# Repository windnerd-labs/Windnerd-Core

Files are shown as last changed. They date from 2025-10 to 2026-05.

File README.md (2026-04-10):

# WindNerd Core - Open Source Sensor & Development Board for 3D-Printed Anemometers

## Intro

The WindNerd Core is a **full magnetic** sensor board designed to fit inside the [**WindNerd 3D-printed-anemometer**](https://github.com/windnerd-labs/Anemometer-3D-files).

It is [**available as a kit**](https://windnerd.net/en/shop), which includes the board and essential parts like magnets and bearings.

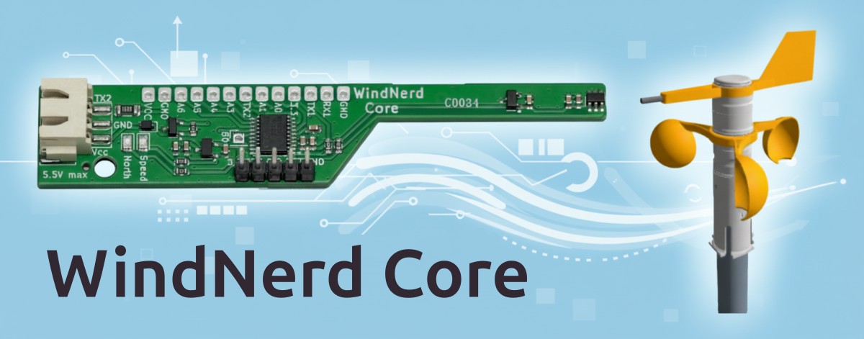
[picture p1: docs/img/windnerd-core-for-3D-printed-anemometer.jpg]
WindNerd Core Sensor/Dev board for 3D-printed anemometer


You can use it as a dedicated wind **sensor module** for your weather station, or as an **Arduino compatible development board** that can, for example:

- Control peripherals such as a [LTE modem](examples/02-lte-modem-A7670X/) to send data remotely
- Drive LEDs that blink according to wind speed and direction
- Interface with other sensors (e.g., temperature, humidity, pressure)

For development, an ST-Link V2 (or compatible) dongle is recommended. However, alternative firmwares can also be uploaded via a serial bootloader.

## Factory Firmware

The board is shipped with factory firmware that outputs instant wind values and averaged wind values over a serial connection.

The average power consumption is only **0.6mA** (3.3V or 5V).

It can be connected to a computer using a **USB-serial-TTL adapter** or to any MCU board that provides a **UART serial interface**.

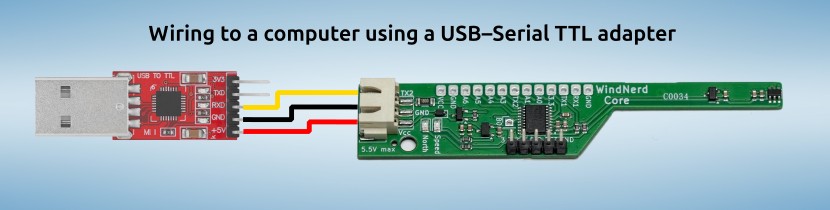
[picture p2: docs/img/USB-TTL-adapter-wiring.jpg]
Wiring WindNerd Core to computer using USB-serial-TTL adapter


The baudrate is 9600bps 8N1. This configuration allows fairly long wiring, e.g. to reach the top of a pole.  

Two types of messages are provided, the default speed unit is km/h and values are averaged for the last 10 minutes:  

**Instant wind** (every 3 Sec)

`WNI,<speed>,<direction 0-359>`
ex: `WNI,10.4,149`  

**Average wind report** (every minute)

`WNA,<speed avg>,<direction avg 0-359>,<min speed>,<max speed>`
ex: `WNA,12.2,93,0,21.4`  

The factory firmware is based on an [Arduino example sketch](examples/01-factory-v1/01-factory-v1.ino) that can be easily tweaked to your own needs.

[**How to read serial data from another device**](docs/READSERIAL.md)

## Arduino library

This repository provides an Arduino library that implements a driver for the magnetic sensors and computes wind speed and direction, exposing the values through a simple API.

[**How to install WindNerd Core library and program the board**](docs/PROGRAM.md)

[**WindNerd Core API reference**](docs/API-REFERENCE.md)

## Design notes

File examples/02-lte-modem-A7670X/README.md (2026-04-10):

# LTE Cat-1 (4G) modem SIMCOM A7670X

## Intro
This example demonstrates how to use a SIMCOM A7670X LTE Cat-1 modem to upload wind data every 2 minutes using the [WindNerd Transfer Protocol](../../docs/WTP.md).

Between uploads modem is is placed into sleep mode to minimize power consumption. Measured system average is ~6 mA to 12mA under good LTE coverage, enabling operation from a single 18650 cell recharged via a small solar panel.

Data consumption is about 40MB per month.

Most SIMCOM and Quectel LTE modems using standard AT command sets should also work with minimal adaptation.

## LTE module

The A7670X exists in multiple regional versions based on LTE band support:

- A7670E Europe, Asia
- A7670SA South America
- A7670G Global

Typical module pricing ranges $10–$25 depending on version.

In this guide we use a A7670E module available for ~$13 on [Aliexpress](https://www.aliexpress.com/item/1005004176439432.html) under the brand "and-global".

## Wiring

### Powered from 5V
The module includes an onboard regulator and can be powered directly from 5V alongside the WindNerd Core. 

Always connect an antenna when powering the module up. 

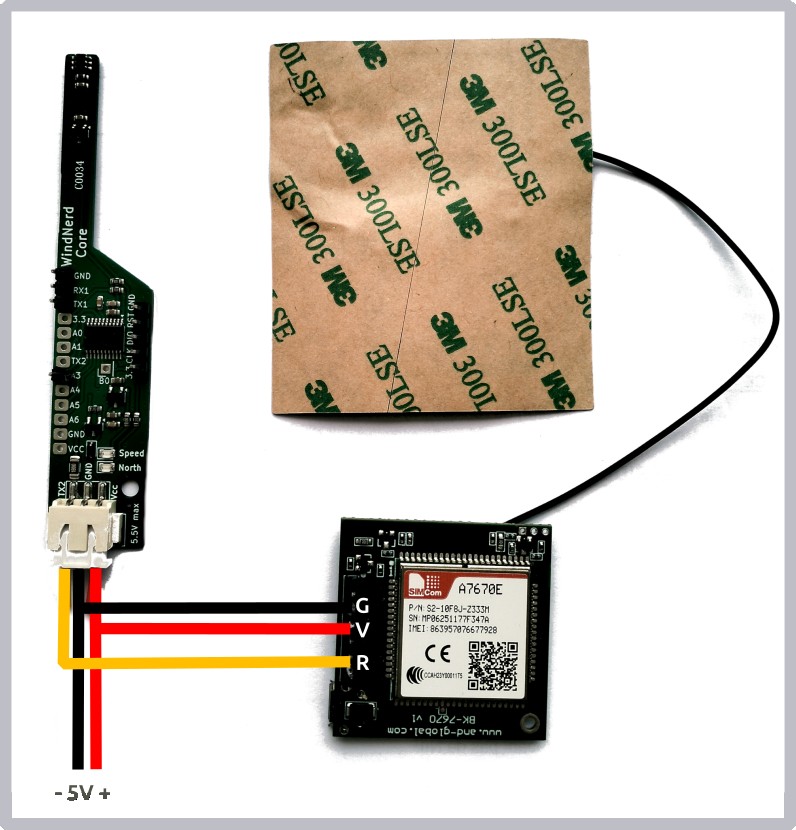
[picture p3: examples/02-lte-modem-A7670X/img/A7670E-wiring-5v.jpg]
Wiring 5V


### Powered from 1 lithium cell

For better efficiency, the A7670X chipset can be powered directly on lithium battery after a little modification on the module. We bypass the inefficient linear voltage regulator and remove a resistance that wastes too much current to the ground.

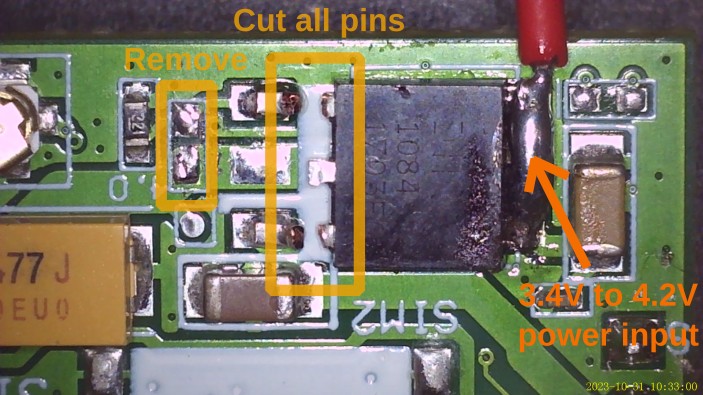
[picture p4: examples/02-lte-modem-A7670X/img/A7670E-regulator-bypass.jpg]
Regulator bypass


Now the battery positive wire should be soldered directly on the board.

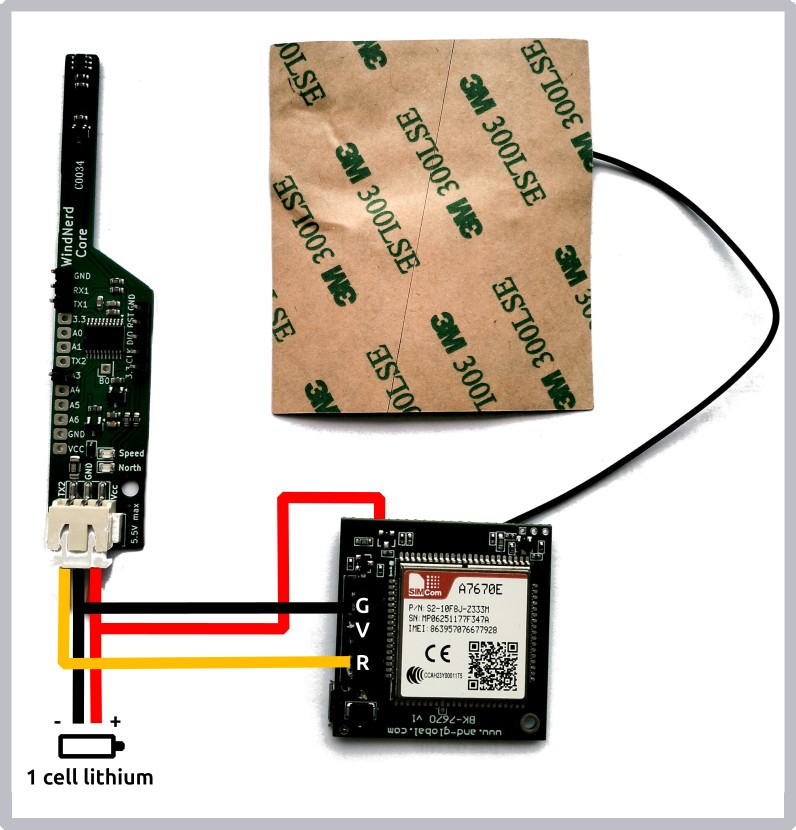
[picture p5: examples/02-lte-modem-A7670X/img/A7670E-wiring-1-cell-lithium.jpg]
Wiring 1-cell Lithium


## WindNerd Core Programming

Open lte-modem-A7670X example sketch, find the line below and replace the secret key with one available on your [windnerd.net dashboard](https://windnerd.net/en/management):

`#define WTP_SECRET_KEY "af3ffa12c4937ddf"`

[Compile and upload](../../docs/PROGRAM.md) the sketch to your WindNerd Core

It may be necessary to specify the APN for the network in use. For example, if you use a Hologram IoT SIM card, uncomment the line and set the APN as follows:

`#define APN "hologram"`

## Commissioning

When powered with a SIM card inserted, the module will automatically attach to the network even without WindNerd Core connected.

On-board LED behavior:

| LED State | Meaning |
| --- | --- |
| On solid after startup | Module boot OK |
| Fast blinking | Connected and data service available |
| OFF | Module powered down or in sleep mode |

Around 2 minutes after powering-up, the station set for your device will show live wind data.

## Power Voltage measurement

It is possible to additionally monitor the supply voltage by soldering two 22 kΩ resistors (or other identical values in the same range, such as 47 kΩ) as a voltage divider between **GND–PB0–VCC**.
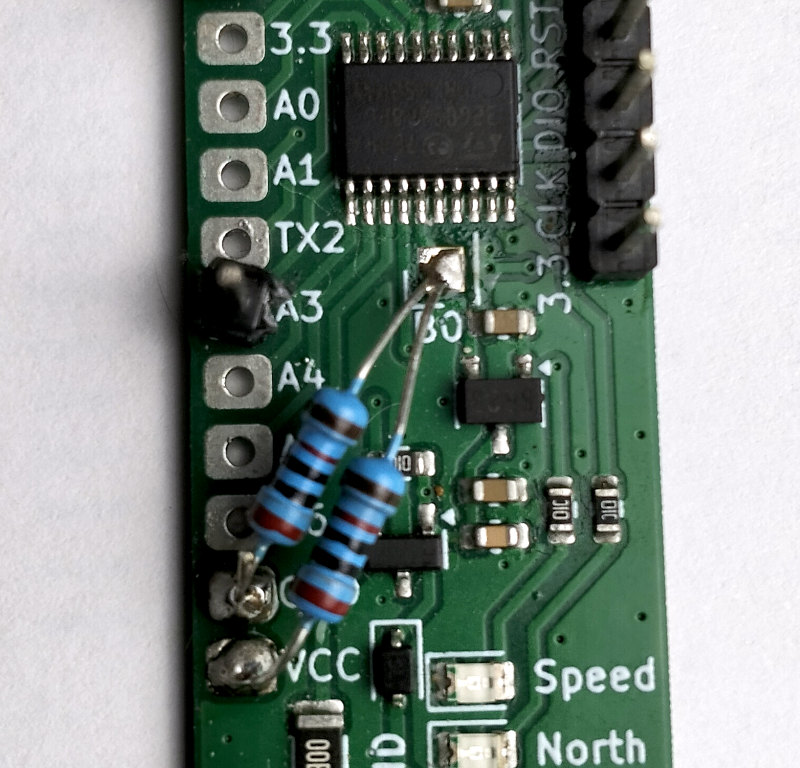
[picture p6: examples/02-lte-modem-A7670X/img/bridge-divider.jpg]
22K resistors soldered on dev board


Uncomment the following line in the sketch to activate the feature
```
#define ENABLE_VOLTAGE
```

## Temperature, humidity, atmospheric pressure measurement

Temperature, humidity, and atmospheric pressure can be monitored by adding a BME280 sensor (or compatible equivalent like BMP280 or YMP280) on the secondary I²C bus, which shares the same pins as USART1. Without a **radiation shield**, temperature and humidity measurements may not be very accurate.

| USART1    | I2C2
 | -----|------- |
| TX1 | SCL2 |
| RX1 | SDA2|

BME280 is powered from GND-3.3V pin headers.

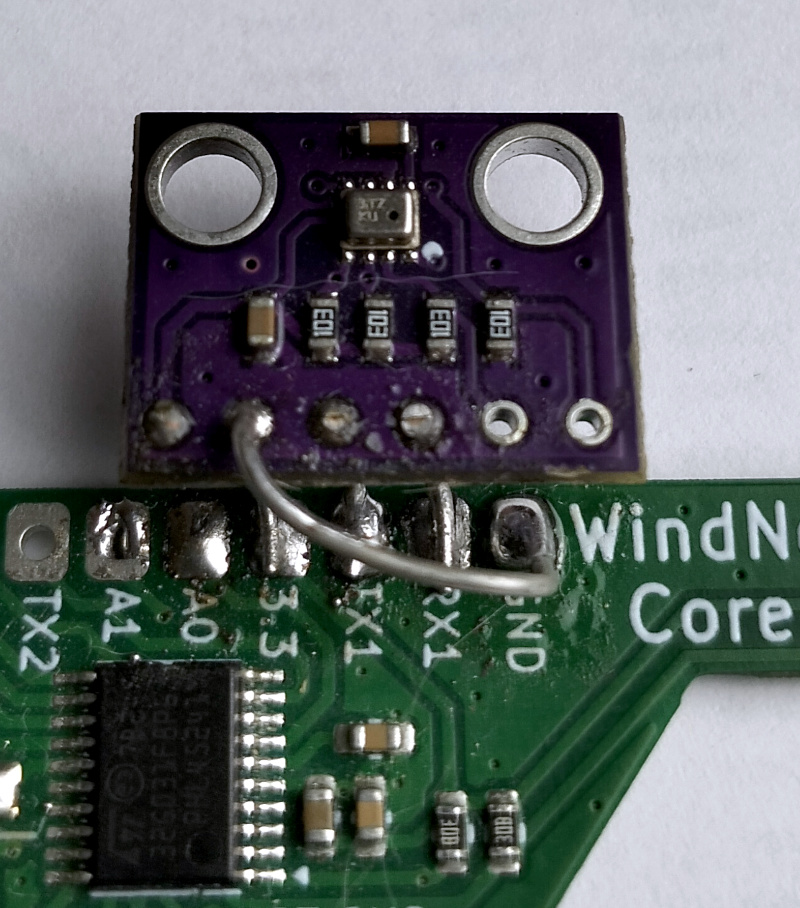
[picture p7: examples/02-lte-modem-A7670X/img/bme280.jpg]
bme280 added to dev board


The Arduino library `Bme280 by Eduard Malokhvii` is required.

Uncomment the following line in the sketch to activate the feature
```
#define ENABLE_BME_280
```

## Debugging (Reading AT Responses)

To inspect the modem’s AT command responses, you can connect a USB-Serial (TTL) adapter to the module’s UART Tx.
This allows you to watch live communication using a terminal such as PuTTY, Screen, or minicom.

| Serial-TTL adapter | A7670X module |
| --- | --- |
| Gnd | Gnd (G) |
| Rx  | Tx (T)  |

### Start-up
When the A7670X powers up with a valid SIM card, it will output several startup notifications.
A typical healthy boot sequence looks like this:

```
[2025-11-10 14:05:24] *ATREADY: 1
[2025-11-10 14:05:24] 
[2025-11-10 14:05:24] *ISIMAID: "A0000000871004F310FFFF89080000FF"
[2025-11-10 14:05:25] 
[2025-11-10 14:05:25] +CPIN: READY
[2025-11-10 14:05:29] 
[2025-11-10 14:05:29] SMS DONE
[2025-11-10 14:05:29] 
[2025-11-10 14:05:29] +CGEV: EPS PDN ACT 1

```

`+CGEV: EPS PDN ACT 1` indicates that the module is attached to network.

### Upload Sequence
Every upload cycle, the sketch sends a small HTTP POST request using the WindNerd Transfer Protocol.

Expected output during a successful upload:

```
[2025-11-10 14:07:19] AT
[2025-11-10 14:07:19] OK
[2025-11-10 14:07:19] AT+HTTPINIT
[2025-11-10 14:07:20] OK
[2025-11-10 14:07:20] AT+HTTPPARA="URL","http://wtp.windnerd.net/post"
[2025-11-10 14:07:20] OK
[2025-11-10 14:07:20] AT+HTTPDATA=765,10000
[2025-11-10 14:07:20] DOWNLOAD
[2025-11-10 14:07:20] 
[2025-11-10 14:07:20] OK
[2025-11-10 14:07:20] AT+HTTPACTION=1
[2025-11-10 14:07:20] OK
[2025-11-10 14:07:22] 
[2025-11-10 14:07:22] +HTTPACTION: 1,200,2
[2025-11-10 14:07:22] AT+HTTPTERM
[2025-11-10 14:07:22] OK
```
`+HTTPACTION: 1,200,2` indicates server responded with HTTP 200 OK

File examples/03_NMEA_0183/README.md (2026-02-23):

# NMEA0183 over serial

## Intro

With this sketch, the WindNerd Core emulates a NMEA 0183 compatible wind sensor.

The communication format follows the NMEA 0183 protocol (ASCII sentences such as $IIMWV,...). However, the electrical characteristics of the WindNerd Core serial output (0–3.3V UART logic level) are not compliant with the official NMEA 0183 electrical standard.

In this example, we connect the WindNerd Core to a computer (for example a Raspberry Pi) using a USB-to-TTL serial converter.

We then configure **Signal K** to treat this serial device as a NMEA 0183 input.

## SignalK configuration

On the Signal K web interface:

- Go to Server → Data Connections

- Click Add

- Create a connection as below

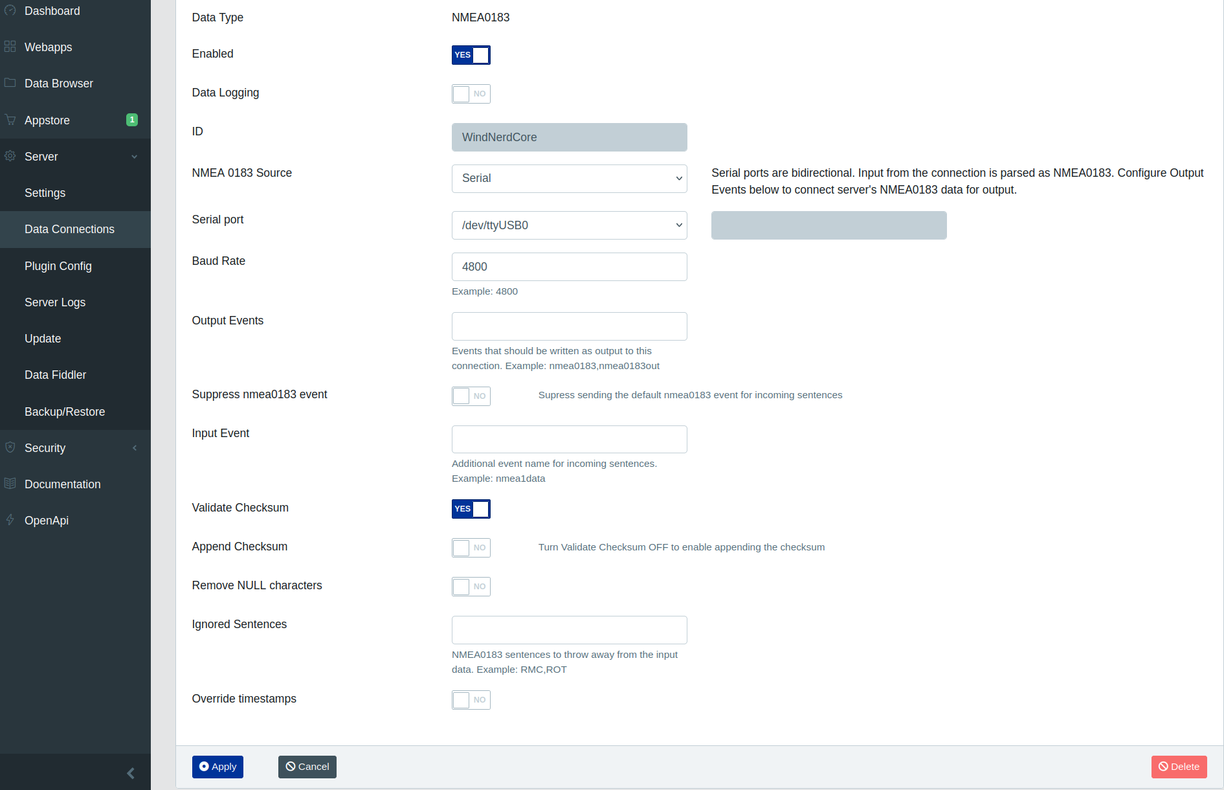
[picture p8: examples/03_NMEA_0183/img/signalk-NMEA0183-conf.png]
Signal K configuration for reading anemometer input


`/dev/ttyUSB0` may be different on your system

If the WindNerd Core is connected and transmitting, wind data should appear in:

Server → Data Browser

You should see path `environment.wind.speedApparent` and `environment.wind.angleApparent` refreshed every 3 seconds.

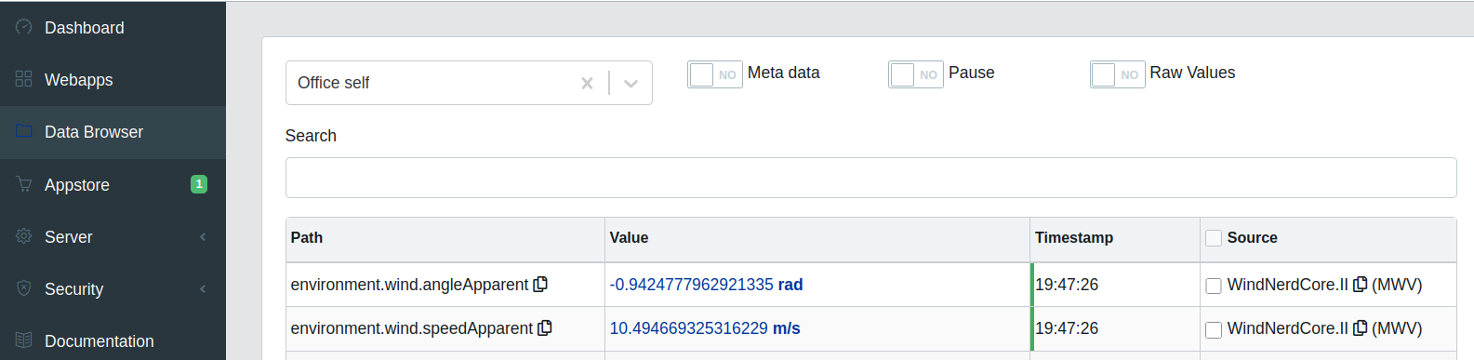
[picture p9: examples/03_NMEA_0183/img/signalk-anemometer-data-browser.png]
Wind data on signalk browser


If nothing appears, try to restart Signal-K server.

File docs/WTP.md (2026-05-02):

# WindNerd Transfer Protocol

## Introduction

The WindNerd Transfer Protocol (WTP) enables recording and broadcasting of fast-changing wind and other weather data even without a permanent internet connection.

Reports with intervals as short as 1 minute can be aggregated and sent in a single request to be recorded and published for your station on **windnerd.net**

High-frequency samples, every 3 seconds, can be sent in real-time or periodically aggregated to be replayed with a delay.

## Authentication

A 16 characters hexadecimal secret key is required, this key is available to WindNerd Core users in their [station management console](https://windnerd.net/en/management). Key can be regenerated at any time.

## Post data

#### Endpoint (use HTTPS if possible):

HTTPS: https://wtp.windnerd.net/post

HTTP:  http://wtp.windnerd.net/post

Two kinds of data can be posted:
 - reports: these reports are stored in windnerd.net database. Average, minimum, and maximum values over longer periods are derived from them.
 - high-frequency wind samples: these samples are broadcast in real time to visualize and feel the wind as it happens. Aggregated samples are queued for delayed replay.
 - logs: health data about the device: internal temperature, power voltage or free form logs.

#### JSON

**Method:** `POST`  
**Content-Type:** `application/json`  
**Responses:** `200 Request accepted`,  `400 Bad Request` or `401 Wrong Authentication`

```json
{
  "secret_key": "3122fd880084fd55",
  "interval_mn": 1,
  "wind_unit": "ms",
  "temp_unit": "C",
  "reports": [
    { "wind_avg": 3.1, "wind_dir": 90,  "wind_min": 0.5, "wind_max": 3.5, "temperature": 22, "humidity": 70, "pressure": 1012 }, // most recent
    { "wind_avg": 1.8, "wind_dir": 45,  "wind_min": 0.0, "wind_max": 2.0, "temperature": 28, "humidity": 85, "pressure": 1016 },
    { "wind_avg": 4.0, "wind_dir": 180, "wind_min": 1.0, "wind_max": 5.0, "temperature": 21, "humidity": 60, "pressure": 1010 },
    { "wind_avg": 2.0, "wind_dir": 200, "wind_min": 0.5, "wind_max": 2.5, "temperature": 23, "humidity": 72, "pressure": 1011 },
    { "wind_avg": 3.5, "wind_dir": 310, "wind_min": 1.5, "wind_max": 4.5, "temperature": 20, "humidity": 65, "pressure": 1009 } // most ancient
  ],
    "samples": [
    { "wind_inst": 3.1, "wind_dir": 90 }, // most recent
    { "wind_inst": 1.8, "wind_dir": 75 },
    { "wind_inst": 4.0, "wind_dir": 110 },
    { "wind_inst": 2.5, "wind_dir": 80 },
    { "wind_inst": 3.3, "wind_dir": 82 },
    { "wind_inst": 0.8, "wind_dir": 101 },
    { "wind_inst": 2.0, "wind_dir": 105 },
    { "wind_inst": 3.5, "wind_dir": 120 },
    { "wind_inst": 1.2, "wind_dir": 130 },
    { "wind_inst": 2.8, "wind_dir": 125 },
    { "wind_inst": 3.0, "wind_dir": 100 },
    { "wind_inst": 2.2, "wind_dir": 92 },
    { "wind_inst": 1.5, "wind_dir": 95 },
    { "wind_inst": 4.2, "wind_dir": 102 },
    { "wind_inst": 3.8, "wind_dir": 120 },
    { "wind_inst": 2.6, "wind_dir": 104 },
    { "wind_inst": 1.9, "wind_dir": 96 },
    { "wind_inst": 3.2, "wind_dir": 85 },
    { "wind_inst": 2.0, "wind_dir": 93 },
    { "wind_inst": 2.1, "wind_dir": 90 } // most ancient
  ],
  "logs": [
    { "voltage": 3.86, "temp_in": 38.2, "meta": "no error" },
    { "voltage": 3.85, "temp_in": 38.4, "meta": "no error" }
  ]
}
```

##### Parameters Fields

| Field | Alt. | Type | Required | Description |
| --- | ----- | --- | --- | --- |
| `secret_key`  | `k` | string  | Yes | Secret key for authentication |
| `interval_mn` | `i` | integer | No | Interval in minutes between reports (max: `60`, default: `1`) |
| `wind_unit` | `wu` | string  | No | Wind speed unit. Accepts `"kmh"`, `"ms"`, `"mph"` (default: `"ms"`) |
| `temp_unit` | `tu` | string  | No | Temperature unit. Accepts `"C"`, `"F"` (default: `"C"`) |
| `reports` | `r` | array | No\* | Array of aggregated reports (max: 20 items) |
| `samples` | `s` | array | No\* | Array of aggregated samples (max: 200 items) |
| `logs` | `l` | array | No\* | Array of aggregated logs (max: 10 items per 10 mn windows) |

\* At least one of `reports`, `samples`, or `logs` must be provided.

##### Report Fields

| Field | Alt. | Type | Required | Min  | Max  | Description |
| --- | ---- | --- | --- | ---- | ---- | --- |
| `wind_avg` | `wa` | number | Yes | 0 | 360  | Vector-averaged wind speed during the interval |
| `wind_min` | `wn` | number | Yes | 0 | 360  | Minimum wind speed during the interval |
| `wind_max` | `wx` | number | Yes | 0 | 360  | Maximum wind speed during the interval |
| `wind_dir` | `wd` | number | Yes | 0 | 360  | Average wind direction in degrees (0–359) |
| `temperature` | `tp` | number | No | -99  | 200  | Ambient temperature |
| `humidity` | `hu` | number | No | 0 | 100  | Relative humidity (%) |
| `pressure` | `pr` | number | No | 200  | 1100 | Atmospheric pressure (hPa) |

##### Sample Fields

| Field | Alt. | Type | Required | Min  | Max  | Description |
| --- | ---- | --- | --- | ---- | ---- | --- |
| `wind_inst` | `wi` | number | Yes | 0 | 360  | Wind speed during the 3 sec interval |
| `wind_dir` | `wd` | number | Yes | 0 | 360  | Wind direction during the 3 sec interval |

##### Log Fields

| Field | Alt. | Type | Required | Min  | Max  | Description |
| --- | ---- | --- | --- | ---- | ---- | --- |
| `voltage` | `vo` | number | No | 0 | 999  | Voltage (V) |
| `rssi` | `rs` | number | No | -999 | 999  | Signal strength indicator (RSSI) |
| `temp_in` | `ti` | number | No | -99  | 200  | Internal temperature |
| `meta` | `mt` | string | No | - | 512  | Free-form payload for debug or metadata. Maximum length: 512 characters. Allowed characters: printable ASCII (0x20–0x7E) except `,` `;` `=`. |

---

#### TEXT

**Method:** `POST`  
**Content-Type:** `text/plain`  
**Responses:** `200 Request accepted`,  `400 Bad Request` or `401 Wrong Authentication`

Alternatively, the payload can be encoded as plain text. 

The first line defines the parameters, and each subsequent line represents a report (line starting with `r`), a sample (line starting with `s`), or a log (line starting with `l`).

Lines are separated by semicolons; end-of-line and carriage return characters are optional.

Report, sample, and log lines must be ordered from most recent to most ancient.

```text
k=3122fd880084fd55,i=1,wu=ms,tu=C;
r,wa=3.1,wd=90,wn=0.5,wx=3.5,tp=22,hu=70,pr=1012;
r,wa=1.8,wd=45,wn=0.0,wx=2.0,tp=28,hu=85,pr=1016;
r,wa=4.0,wd=180,wn=1.0,wx=5.0,tp=21,hu=60,pr=1010;
r,wa=2.0,wd=200,wn=0.5,wx=2.5,tp=23,hu=72,pr=1011;
r,wa=3.5,wd=310,wn=1.5,wx=4.5,tp=20,hu=65,pr=1009;
l,vo=3.86,ti=38.2,mt=no error;
s,wi=3.1,wd=90;
s,wi=1.8,wd=75;
s,wi=4.0,wd=110;
s,wi=2.5,wd=80;
s,wi=3.3,wd=82;
s,wi=0.8,wd=101;
s,wi=2.0,wd=105;
s,wi=3.5,wd=120;
s,wi=1.2,wd=130;
s,wi=2.8,wd=125;
s,wi=3.0,wd=100;
s,wi=2.2,wd=92;
s,wi=1.5,wd=95;
s,wi=4.2,wd=102;
s,wi=3.8,wd=120;
s,wi=2.6,wd=104;
s,wi=1.9,wd=96;
s,wi=3.2,wd=85;
```

## Examples in context

### Permanent connection
A Raspberry Pi in a ceiling, connected to WindNerd Core, has continuous power and internet access. JSON format is handled easily and we can send data without limitation. 

We post high-frequency samples every 3 seconds:

```json
{
  "v": 1,
  "k": "3122fd880084fd55",
  "wind_unit": "ms",
  "samples": [
    { "wind_inst": 3.1, "wind_dir": 90 }
  ]
}
```

We post a report every minute:
```json
{
  "secret_key": "3122fd880084fd55",
  "interval_mn": 1,
  "wind_unit": "ms",
  "temp_unit": "C",
  "reports": [
    { "wind_avg": 3.1, "wind_dir": 90,  "wind_min": 0.5, "wind_max": 3.5, "temperature": 22, "humidity": 70, "pressure": 1012 },
  ]
}
```
---

### Limited radio use
A WindNerd Core is connected to a LoRa development board and installed at a paragliding takeoff. The LoRa receiver has permanent power and internet access, but fair-use limitations allow only one transmission per minute.

We connect every minute to send aggregated reports and high-frequency samples. To keep messages short and easy to construct, we use the plain-text format. Pilots can still see a real-time wind animation, with a 1-minute delay due to the transmission interval.

We post 20 samples and a report every minute:

```text
k=3122fd880084fd55,wu=ms;
r,wa=3.1,wd=90,wn=0.5,wx=3.5;
s,wi=3.1,wd=90;
s,wi=1.8,wd=75;
s,wi=4.0,wd=110;
s,wi=2.5,wd=80;
s,wi=3.3,wd=82;
s,wi=0.8,wd=101;
s,wi=2.0,wd=105;
s,wi=3.5,wd=120;
s,wi=1.2,wd=130;
s,wi=2.8,wd=125;
s,wi=3.0,wd=100;
s,wi=2.2,wd=92;
s,wi=1.5,wd=95;
s,wi=4.2,wd=102;
s,wi=3.8,wd=120;
s,wi=2.6,wd=104;
s,wi=1.9,wd=96;
s,wi=3.2,wd=85;
s,wi=2.0,wd=93;
s,wi=2.1,wd=90;
```
---

### Limited power

A WindNerd Core is connected to a 4G modem development board and installed at a remote location. Power is limited because it relies on a small solar cell and battery, and winter nights are long.

We activate a power-saving mode, making a connection only every 20 minutes. During each connection, we send 20 1-minute reports. Data are no longer real-time, but all detailed history is preserved.

We post 20 reports every 20 minute:

```text
k=3122fd880084fd55,i=1,wu=ms;
r,wa=2.1,wd=180,wn=1.0,wx=2.5,tp=0.2,hu=88,pr=1018.0;
r,wa=1.8,wd=190,wn=0.5,wx=2.0,tp=0.3,hu=89,pr=1018.1;
r,wa=2.5,wd=175,wn=1.2,wx=3.0,tp=0.2,hu=87,pr=1018.0;
r,wa=1.9,wd=200,wn=0.8,wx=2.3,tp=0.1,hu=90,pr=1018.1;
r,wa=2.2,wd=185,wn=0.9,wx=2.8,tp=0.2,hu=88,pr=1018.0;
r,wa=2.0,wd=170,wn=0.7,wx=2.5,tp=0.2,hu=89,pr=1018.1;
r,wa=2.8,wd=195,wn=1.0,wx=3.2,tp=0.3,hu=87,pr=1018.0;
r,wa=1.5,wd=180,wn=0.5,wx=1.9,tp=0.1,hu=91,pr=1018.0;
r,wa=2.3,wd=210,wn=1.0,wx=2.7,tp=0.2,hu=88,pr=1018.1;
r,wa=2.6,wd=190,wn=1.2,wx=3.0,tp=0.2,hu=89,pr=1018.0;
r,wa=2.0,wd=175,wn=0.8,wx=2.4,tp=0.1,hu=90,pr=1018.0;
r,wa=2.7,wd=200,wn=1.0,wx=3.1,tp=0.2,hu=87,pr=1018.1;
r,wa=1.9,wd=185,wn=0.7,wx=2.5,tp=0.2,hu=88,pr=1018.0;
r,wa=2.4,wd=170,wn=1.0,wx=2.9,tp=0.3,hu=89,pr=1018.1;
r,wa=2.1,wd=195,wn=0.8,wx=2.6,tp=0.2,hu=90,pr=1018.0;
r,wa=2.5,wd=180,wn=1.1,wx=3.0,tp=0.2,hu=88,pr=1018.0;
r,wa=2.2,wd=200,wn=0.9,wx=2.7,tp=0.2,hu=87,pr=1018.1;
r,wa=1.8,wd=190,wn=0.5,wx=2.2,tp=0.1,hu=90,pr=1018.0;
r,wa=2.3,wd=175,wn=0.8,wx=2.8,tp=0.2,hu=89,pr=1018.1;
r,wa=2.0,wd=185,wn=0.7,wx=2.5,tp=0.2,hu=88,pr=1018.0;

```

Samples are omitted.

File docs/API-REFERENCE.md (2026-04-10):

# WindNerd Core API Reference

The WindNerd Core library provides wind speed and direction measurements from the WindNerd Core sensor board or alternative board based on same design.

Internally it:

- counts rotor pulses to compute wind speed
- reads the TMAG5273 magnetic sensor for wind direction
- samples data periodically
- stores samples in a rolling buffer
- computes averaged/min/max wind reports
- controls the diagnostic LEDs: speed LED blinks at each rotation, north LED turns ON when the vane is indicating north

Applications can obtain data using either:

- Pull-based access (poll samples or reports when needed)
- Push-based access (receive updates via callbacks)

## 1. Minimal Setup

The minimal setup runs the anemometer and lets you retrieve wind data from the internal buffer.

The user must:

1. Instantiate WN_Core
2. Call begin()
3. Call loop() frequently
4. Pull samples when needed

Example

```
#include <Windnerd_Core.h>

WN_Core Anemometer;

void setup() {
    Anemometer.begin();
}

void loop() {
    Anemometer.loop();

    // read the latest sample
    wn_instant_wind_sample_t sample = Anemometer.getSampleIndexedFromLast(0);

    Serial.print("Speed: ");
    Serial.print(sample.speed);
    Serial.print(" Direction: ");
    Serial.println(sample.dir);
}

```

What happens internally:
- Rotor pulses are counted using interrupts
- Direction is sampled periodically and averaged over 3 seconds
- Every 3 seconds a new wind sample (instant speed + wind direction) is generated
- Samples are stored in a rolling buffer

If Arduino loop() is blocked too long (>50ms), samples may be dropped.

## 2. Pull Model (Polling Data)

In the pull model, your application retrieves wind data whenever it wants.

This is useful when:

- your firmware already has its own scheduler
- you want full control over when data is processed

### Get the Latest Sample

```
wn_instant_wind_sample_t sample = Anemometer.getSampleIndexedFromLast(0);
```
Structure:

```
wn_instant_wind_sample_t
{
    float speed;
    uint16_t dir;
}
```

Fields:

| Field | Description |
| ----- | --- |
| speed | wind speed in selected unit (default m/s)  |
| dir | direction in degrees (0-359) |

The rolling buffer stores samples for the last 20 minutes (400 samples)

index 0 → newest sample

index 1 → previous sample

index N → older samples

Example:
```
wn_instant_wind_sample_t sample = Anemometer.getSampleIndexedFromLast(5);
```

### Compute Average Wind Report

Compute statistics over the most recent period for a duration given in seconds.

Example for the last minute:
```
wn_wind_report_t report = Anemometer.computeReportForRecentPeriodInSec(60);
```

Structure:
```
wn_wind_report_t
{
    float avg_speed;
    float min_speed;
    float max_speed;
    uint16_t avg_dir;
}
```

Fields:

| Field | Description |
| --- | --- |
| avg_speed | average wind speed |
| min_speed | minimum wind speed |
| max_speed | maximum wind speed |
| avg_dir | vector-averaged wind direction |

Alternatively, `computeReportForPeriodInSecIndexedFromLast` allows to compute a report for an anterior period of time

For example:
```
  wn_wind_report_t report = Anemometer.computeReportForPeriodInSecIndexedFromLast(60, 1);
```
This creates a report for the period between 2 minutes ago and 1 minute ago.

## 3. Push Model (Callbacks)

In the push model, the library calls your code whenever new wind data is available.

This is useful when:

- you want event-driven firmware
- you want to minimize polling
- you want immediate processing of new measurements

### Instant Wind Callback

Called every sampling window (~3 seconds).

```
void onInstantWind(wn_instant_wind_sample_t sample)
{
    Serial.print("Speed: ");
    Serial.println(sample.speed);
}

void setup()
{
    Anemometer.onInstantWindUpdate(onInstantWind);
}

```

### Average Wind Report Callback

Called at the configured reporting interval.
```
void onWindReport(wn_wind_report_t report)
{
    Serial.print("Avg speed: ");
    Serial.println(report.avg_speed);
}

void setup()
{
    Anemometer.onNewWindReport(onWindReport);
}
```

## 4. Configuration

The library exposes configuration functions to adapt behavior to different installations.

### Set Speed Units

```
Anemometer.setSpeedUnit(UNIT_MS);
```

Available units:

| Unit | Description |
| --- | --- |
| UNIT_MS  | meters per second |
| UNIT_KN  | knots |
| UNIT_KPH | kilometers per hour |
| UNIT_MPH | miles per hour |

### Adjust the conversion between rotor frequency and wind speed.

```
Anemometer.setFrequencyToWindSpeedRatio(1.31);

```
Default value `1.31` corresponds to the standard WindNerd rotor.

### Set Averaging Period

Controls how long wind data is averaged when using push mode.

```
Anemometer.setAveragingPeriodInSec(60);
```

Constraints:

period >= 3 seconds

period <= 1200 seconds

### Set Reporting Interval

Controls how often a wind report is produced when using push mode.

```
Anemometer.setReportingIntervalInSec(60);
```
Example:

| Averaging | Reporting |
| --- | --- |
| 600s | 60s |

This produces a rolling 600-second average updated every 60 seconds.

### Invert Vane Polarity

Depending on how the vane magnet was mounted, you may need to invert the polarity if you notice south and north are inverted.

```
Anemometer.invertVanePolarity(true);
```

## 5. Low Power Mode

Low power mode reduces vane measurement frequency.

```
Anemometer.enableLowPowerMode();
```

Behavior changes:

| Feature | Normal | Low Power |
| --- | --- | --- |
| vane sampling | every 100 ms | every 500 ms |
| LED activity  | enabled | disabled |

Disable with:
```
Anemometer.disableLowPowerMode();
```

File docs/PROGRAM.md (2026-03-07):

# How to program the WindNerd Core

## Install STM32CubeProgrammer

To upload sketches using ST-Link (SWD), you must install STM32CubeProgrammer.

- Download STM32CubeProgrammer from the STMicroelectronics website (for Windows, MacOS or Linux):
https://www.st.com/en/development-tools/stm32cubeprog.html

- Install the software for your operating system following the instructions from STMicroelectronics

During installation, make sure the following components are installed:

- STM32CubeProgrammer

- ST-Link drivers

After installation, connect your ST-Link programmer and verify it works:

- Start STM32CubeProgrammer

- Select ST-Link

- Click Connect

If the connection succeeds, your system is ready to upload firmware from the Arduino IDE.

## Download and install Arduino IDE 2 

https://docs.arduino.cc/software/ide-v2/tutorials/getting-started/ide-v2-downloading-and-installing/

## Add support for STM32 boards

Launch Arduino IDE. Click on "File" menu and then "Preferences".

The "Preferences" dialog will open, then add the following link to the "Additional Boards Managers URLs" field:

https://github.com/stm32duino/BoardManagerFiles/raw/main/package_stmicroelectronics_index.json

## Install WindNerd Core Arduino Library

### Via Library manager (available soon)

1. Go to **Sketch → Include Library → Manage Libraries…**.

2. In the Library Manager window, type `WindNerd Core` in the search bar.

3. Locate the **WindNerd Core** entry in the results.

4. Click **Install**.

5. Once installed, you can access the example sketches via **File → Examples → WindNerd-Core**.

Using the Library Manager is the easiest way to keep the library up to date.

### Manually

To install the library manually:

1. **Download or clone the repository** from [https://github.com/windnerd-labs/Windnerd-Core](https://github.com/windnerd-labs/Windnerd-Core).  
   - If you download as ZIP, extract it.  
   - If you clone with Git:  
     ```bash
     git clone https://github.com/windnerd-labs/Windnerd-Core.git
     ```

2. **Copy the `Windnerd-Core` folder** into your Arduino libraries folder:  
   - **Windows**: `Documents\Arduino\libraries\`  
   - **macOS**: `~/Documents/Arduino/libraries/`  
   - **Linux**: `~/Arduino/libraries/`

3. **Restart Arduino IDE**.  
   You should now see **Windnerd-Core** in **File → Examples**.

## Set the board

1. **Select the board:**
   - Go to **Tools → Board → STM32 Boards MCU based boards**. 

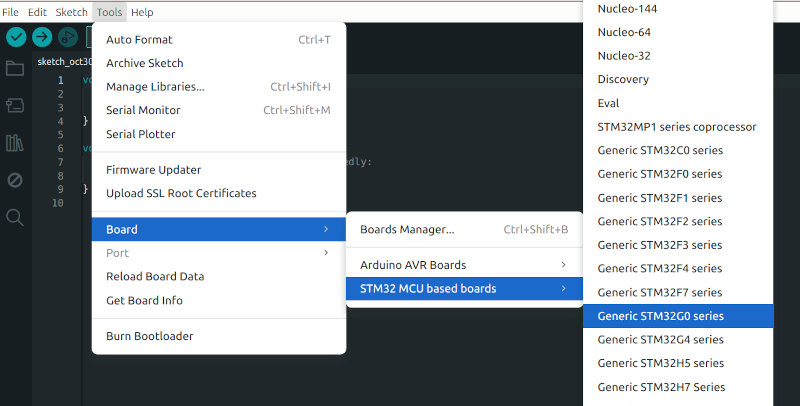
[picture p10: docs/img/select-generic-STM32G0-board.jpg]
How to select generic STM32G0-board from Arduino menu
   
   - Choose **Generic STM32G031F8Px**.

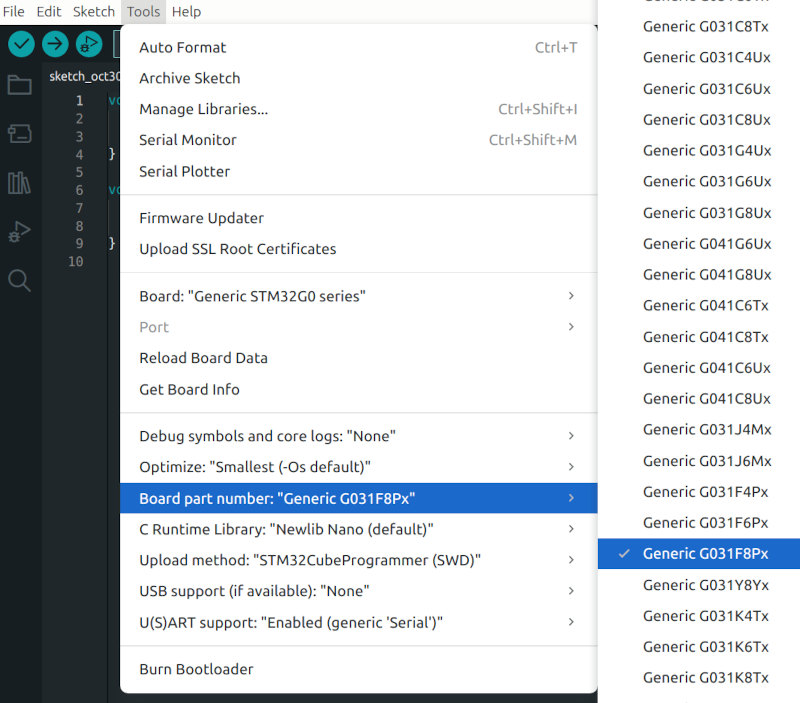
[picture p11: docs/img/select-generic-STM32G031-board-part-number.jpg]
How to select generic STM32G031 part number from Arduino menu
   

2. **Set the upload method:**
   - Go to **Tools → Upload Method**.
   - For STM32G0 series, choose:
     - **STM32CubeProgrammer (SWD)** if you are using an ST-Link **(recommended)**. Connect pins CLK,DIO,RST and GND to your ST-link dongle. Power supply can either be provided through VCC or 3.3V (supplied by the ST-Link) but do not connect both at same time.

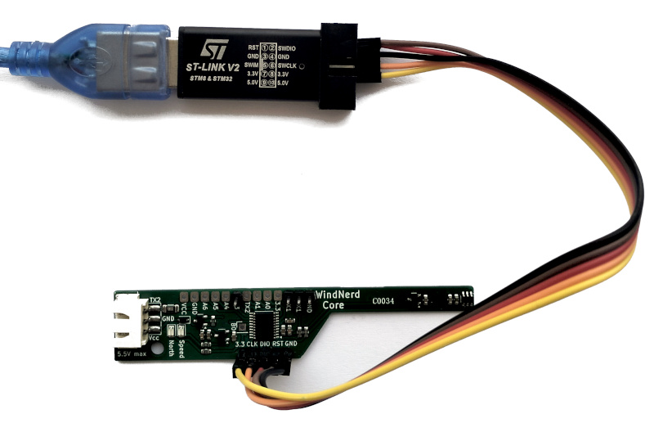
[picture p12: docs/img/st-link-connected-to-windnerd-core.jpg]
How to connect ST Link programmer to WindNerd Core
     
     - **Serial** if you are using a USB Serial-TTL adapter connected to RX1 and TX1. This mode needs to be enabled on the board by placing a jumper between pin headers named CLK and 3.3 and repowering the board.  

4. **Upload a sketch** as usual using the **Upload** button.

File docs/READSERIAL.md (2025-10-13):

# How to read WindNerd Core serial from another device

## From a Computer

Wiring WindNerd Core to computer using USB-serial-TTL adapter

### Serial terminal

#### Linux

`minicom -D /dev/ttyUSB0 -b 9600`

The serial device name can also be enumerated as `/dev/ttyUSB1`, `/dev/ttyUSB2` etc if several serial adpaters are present. Some serial adapters can be listed as `/dev/ttyACM0`, `/dev/ttyACM1`...

#### Windows

- Download and install [Putty](https://pbxbook.com/voip/sputty.html)
- Open PuTTY
- Select Serial
- Enter COM1 (or COM2, COM3 etc)
- Set Speed to 9600
- Click Open

#### MacOS

- Install minicom with `brew install minicom`
- Find the serial adapter name with  `ls /dev/cu.* /dev/tty.* 2>/dev/null`
- Run minicom with the adapter name found, eg: `minicom -D /dev/cu.usbserial-xxxx -b 9600`

### NodeJS

```
const { SerialPort, ReadlineParser } = require('serialport');

// Change this to your detected serial port, e.g. "/dev/ttyUSB0" or "/dev/cu.usbserial-1420"
const PORT = '/dev/ttyUSB0';
const BAUD = 9600;

// Open serial port
const port = new SerialPort({ path: PORT, baudRate: BAUD });

// Create a line-based parser (splits on newline)
const parser = port.pipe(new ReadlineParser({ delimiter: '\n' }));

// Listen for parsed lines
parser.on('data', (line) => {

  console.log(line);
  line = line.trim();
  if (!line) return;

  const parts = line.split(',');
  const tag = parts[0];

  if (tag === 'WNI' && parts.length === 3) {
    const speed = parseFloat(parts[1]);
    const dir = parseFloat(parts[2]);
    console.log(`[Instant Wind] speed=${speed.toFixed(1)} km/h, dir=${dir}°`);
  }

  else if (tag === 'WNA' && parts.length === 5) {
    const avgSpeed = parseFloat(parts[1]);
    const avgDir = parseFloat(parts[2]);
    const minSpeed = parseFloat(parts[3]);
    const maxSpeed = parseFloat(parts[4]);
    console.log(`[Wind Report] avg=${avgSpeed.toFixed(1)} km/h, dir=${avgDir}°, min=${minSpeed.toFixed(1)}, max=${maxSpeed.toFixed(1)}`);
  }

  else {
    console.warn('Unknown line:', line);
  }
});

port.on('open', () => {
  console.log(`Serial connected on ${PORT} at ${BAUD} baud`);
});

port.on('error', (err) => {
  console.error('Serial error:', err.message);
});
```

### Python

## From an Arduino dev board

### Hardware Serial

### Software Serial

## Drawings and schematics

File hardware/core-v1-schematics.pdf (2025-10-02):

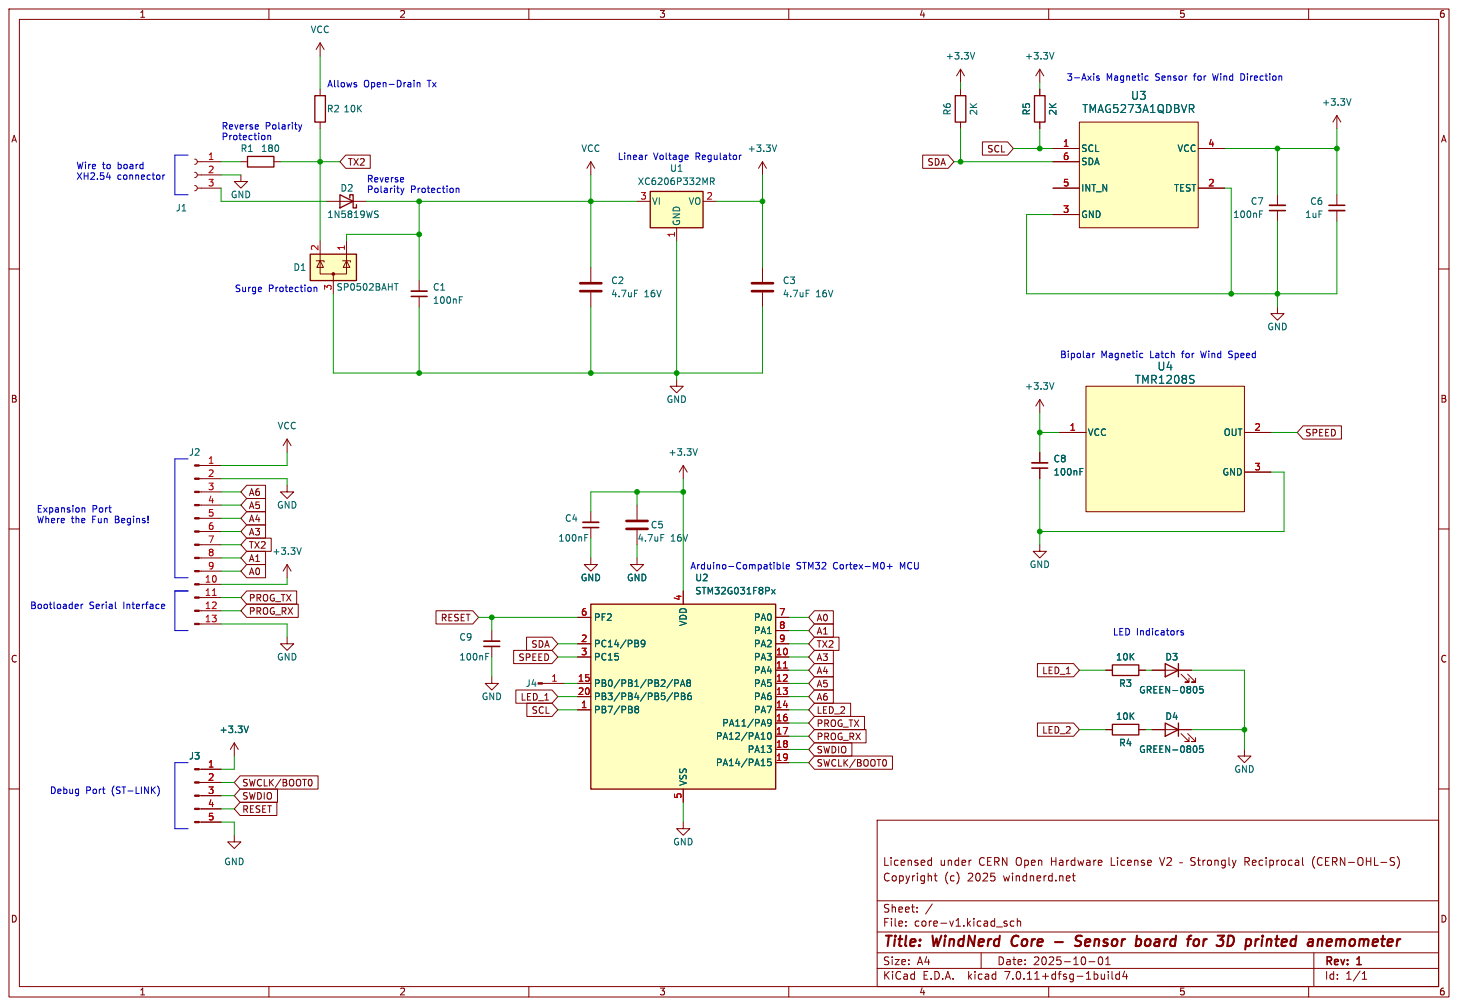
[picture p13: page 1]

Debug Port (ST-LINK)

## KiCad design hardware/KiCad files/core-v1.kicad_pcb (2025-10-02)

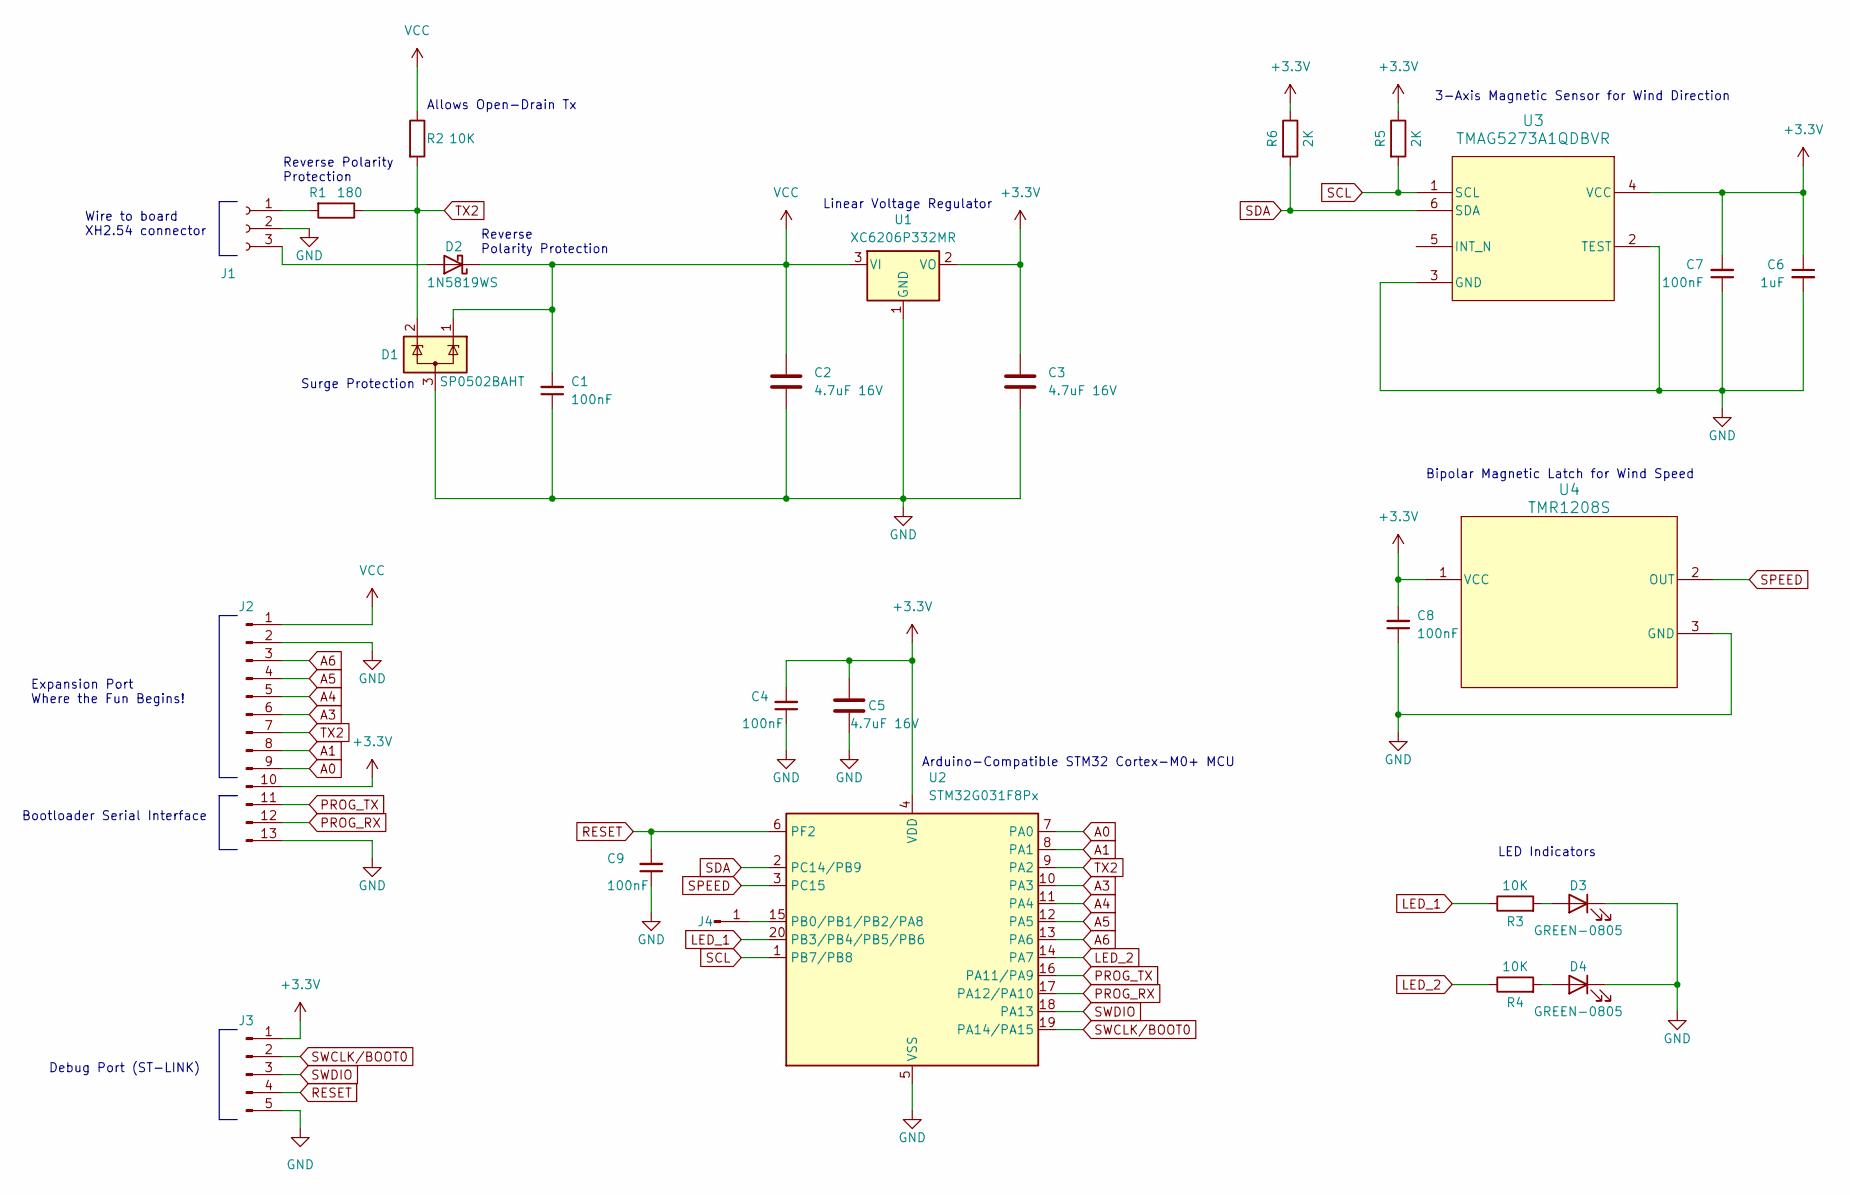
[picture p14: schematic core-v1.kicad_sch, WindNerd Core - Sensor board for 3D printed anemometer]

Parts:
C1, C4, C7, C8, C9: 100nF; C_0603_1608Metric
C2, C3, C5: 4.7uF 16V; C_0603_1608Metric
C6: 1uF; C_0603_1608Metric
D1: SP0502BAHT; SOT-23
D2: 1N5819WS; D_SOD-323
D3, D4: GREEN-0805; LED_0805_2012Metric
J1: XH2.54-3P SMD; ZX-XH2.54-3
J2: Conn_01x13_Pin; PinHeader_1x13_P2.54mm_Vertical
J3: Conn_01x05_Pin; PinHeader_1x05_P2.54mm_Vertical
J4: Conn_01x01_Pin; PinHeader_1x01_P2.54mm_Vertical
R1: 180; R_1206_3216Metric
R2, R3, R4: 10K; R_0603_1608Metric
R5, R6: 2K; R_0603_1608Metric
U1: XC6206P332MR; SOT-23-3
U2: STM32G031F8Px; TSSOP-20_4.4x6.5mm_P0.65mm
U3: TMAG5273A1QDBVR; SOT-23-6
U4: TMR1208S; SOT-23

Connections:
+3.3V: C3.1, C4.2, C5.1, C6.1, C7.2, C8.2, J2.10, J3.1, R5.1, R6.1, U1.2 (VO), U2.4 (VDD), U3.4 (VCC), U4.1 (VCC)
A0: J2.9, U2.7 (PA0)
A1: J2.8, U2.8 (PA1)
A3: J2.6, U2.10 (PA3)
A4: J2.5, U2.11 (PA4)
A5: J2.4, U2.12 (PA5)
A6: J2.3, U2.13 (PA6)
GND: C1.1, C2.2, C3.2, C4.1, C5.2, C6.2, C7.1, C8.1, C9.1, D1.3 (A), D3.1 (K), D4.1 (K), J1.2, J2.2, J2.13, J3.5, U1.1 (GND), U2.5 (VSS), U3.2 (TEST), U3.3 (GND), U4.3 (GND)
LED_1: R3.1, U2.20 (PB3/PB4/PB5/PB6)
LED_2: R4.1, U2.14 (PA7)
unnamed: D2.2 (A), J1.3
unnamed: D3.2 (A), R3.2
unnamed: D4.2 (A), R4.2
unnamed: J1.1, R1.2
unnamed: J4.1, U2.15 (PB0/PB1/PB2/PA8)
PROG_RX: J2.12, U2.17 (PA12/PA10)
PROG_TX: J2.11, U2.16 (PA11/PA9)
RESET: C9.2, J3.4, U2.6 (PF2)
SCL: R5.2, U2.1 (PB7/PB8), U3.1 (SCL)
SDA: R6.2, U2.2 (PC14/PB9), U3.6 (SDA)
SPEED: U2.3 (PC15), U4.2 (OUT)
SWCLK/BOOT0: J3.2, U2.19 (PA14/PA15)
SWDIO: J3.3, U2.18 (PA13)
TX2: D1.2 (K), J2.7, R1.1, R2.2, U2.9 (PA2)
VCC: C1.2, C2.1, D1.1 (K), D2.1 (K), J2.1, R2.1, U1.3 (VI)

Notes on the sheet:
3-Axis Magnetic Sensor for Wind Direction
Bipolar Magnetic Latch for Wind Speed
Linear Voltage Regulator
Wire to board XH2.54 connector
Bootloader Serial Interface
Reverse Polarity Protection
Surge Protection
Expansion Port Where the Fun Begins!
Arduino-Compatible STM32 Cortex-M0+ MCU
Debug Port (ST-LINK)
Allows Open-Drain Tx
Reverse Polarity Protection
LED Indicators

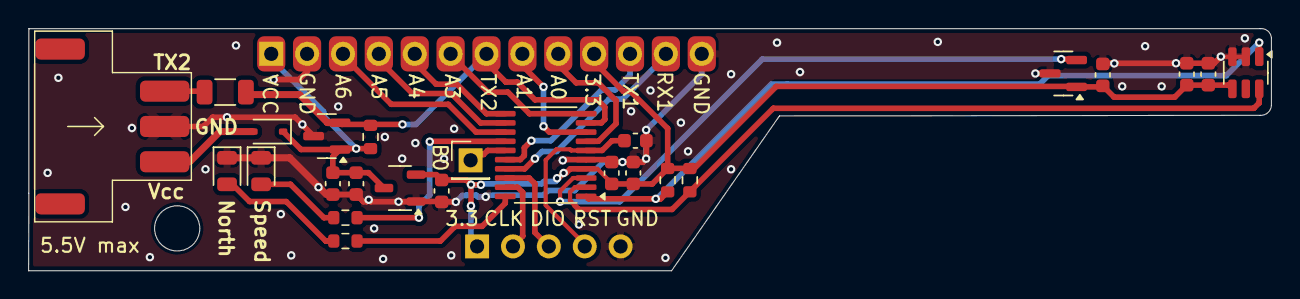
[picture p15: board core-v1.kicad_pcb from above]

Board: 2 copper layers, 88.0 x 17.1 mm, 27 parts (0 on the bottom side), 25 nets.

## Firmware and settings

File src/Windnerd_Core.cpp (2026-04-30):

/*
 * Copyright (c) 2025, windnerd.net
 * All rights reserved.
 *
 * This source code is licensed under the BSD 3-Clause License found in the
 * LICENSE file in the root directory of this source tree.
 */

#include "Windnerd_Core.h"
#include "Windnerd_TMAG5273.h"
#include <HardwareTimer.h>
#include <Wire.h>

HardwareTimer *tickerTimer = nullptr;

// frequency to speed ratio for standard rotor
#define HZ_TO_MS 1.31

// default wind vector averaging period in seconds
#define DEFAULT_AVG_PERIOD_SEC 60
// default time between wind avg update in seconds
#define DEFAULT_UPDATE_PERIOD_SEC 60

// 30 ticks at 10 HZ -> speed pulses are counted for each 3 sec periods
#define TICK_HZ 10
#define SAMPLING_WINDOW_TICKS 30
#define SAMPLE_DURATION (SAMPLING_WINDOW_TICKS / TICK_HZ)

// in low power mode, measure vane angle every 500 ms
#define LOW_POWER_VANE_TICKS 5

static volatile bool wn_ticker = false;         // flag to indicate that a tick interrupt has happened
static volatile uint32_t speed_pulse_count = 0; // to be incremented by rising edge interrupts on speed pulse input
static volatile bool low_power_mode = false;
static volatile uint8_t isr_speed_led_pin = CORE_SPEED_LED_PIN;


void onSpeedPulseISR()
{
  if (!low_power_mode)
    digitalWrite(isr_speed_led_pin, HIGH); // signal pulse by turning the speed LED ON, it will be turned OFF during the next tick
  speed_pulse_count++;
}

void onTickerTimerISR()
{
  wn_ticker = true;
}

WN_Core::WN_Core(
    uint8_t speed_led_pin,
    uint8_t north_led_pin,
    uint8_t speed_input_pin,
    uint8_t scl_pin,
    uint8_t sda_pin
)
    : _speed_led_pin(speed_led_pin),
      _north_led_pin(north_led_pin),
      _speed_input_pin(speed_input_pin),
      _scl_pin(scl_pin),
      _sda_pin(sda_pin),
      _HZ_to_ms(HZ_TO_MS),
      _wind_average_period_sec(DEFAULT_AVG_PERIOD_SEC),
      _wind_update_period_sec(DEFAULT_UPDATE_PERIOD_SEC)
{
  isr_speed_led_pin = _speed_led_pin;
}

void WN_Core::begin()
{

  // turn on all LEDs so the board shows life a startup
  pinMode(_speed_led_pin, OUTPUT);
  digitalWrite(_speed_led_pin, HIGH);

  pinMode(_north_led_pin, OUTPUT);
  digitalWrite(_north_led_pin, HIGH);

  Wire.setSDA(_sda_pin);
  Wire.setSCL(_scl_pin);

  wn_init_angle_sensor(_scl_pin, _sda_pin);

  tickerTimer = new HardwareTimer(TIM3);
  tickerTimer->setOverflow(TICK_HZ, HERTZ_FORMAT);
  tickerTimer->attachInterrupt(onTickerTimerISR);
  tickerTimer->resume();

  pinMode(_speed_input_pin, INPUT);
  attachInterrupt(digitalPinToInterrupt(_speed_input_pin), onSpeedPulseISR, RISING);
  last_sampling_window_millis = millis();
}


// set the averaging period for average wind report
bool WN_Core::setAveragingPeriodInSec(uint16_t period)
{
  if (period >= SAMPLE_DURATION && period <= ROLLING_BUFFER_LENGTH * SAMPLE_DURATION)
  {
    _wind_average_period_sec = period;
    return true;
  }
  else
  {
    return false;
  }
}

// set the time interval between average wind reports
bool WN_Core::setReportingIntervalInSec(uint16_t period)
{
  if (period >= SAMPLE_DURATION)
  {
    _wind_update_period_sec = period;
    return true;
  }
  else
  {
    return false;
  }
}

void WN_Core::invertVanePolarity(bool should_invert)
{
  _invert_polarity = should_invert;
}

// set an alternative rotor frequency to wind speed ratio (Hz to m/s)
void WN_Core::setFrequencyToWindSpeedRatio(float ratio)
{
  _HZ_to_ms = ratio;
}

// turn on North led when vane is roughly north
void WN_Core::signalIfNorth(uint16_t angle)
{

  if (!low_power_mode && (angle > 355 || angle < 5))
  {
    digitalWrite(_north_led_pin, HIGH);
  }
  else
  {
    digitalWrite(_north_led_pin, LOW);
  }
}

void WN_Core::loop()
{

  if (!wn_ticker)
    return;
  wn_ticker = false;

  ticks_cnt++;

  if (!low_power_mode || ticks_cnt % LOW_POWER_VANE_TICKS == 0)
  {

    uint16_t angle = wn_read_then_make_angle_sensor_sleep();

    if (_invert_polarity)
    {
      angle = angle + 180;
    }

    angle = angle % 360; // cap value from 0 to 359
    signalIfNorth(angle);

    // accumulate with an arbitrary magnitude, we are interested only in direction avg
    VaneAverager.accumulate((uint32_t)1, angle);
  }

  // reset the speed led for flash effect
  digitalWrite(_speed_led_pin, LOW);

  if (ticks_cnt % SAMPLING_WINDOW_TICKS == 0)
  { // counting window has elapsed

    // check timing, drop the sample if one or more ticks were missed (would be likely caused by a blocking delay in user program loop)
    if (millis() - last_sampling_window_millis < SAMPLE_DURATION * 1000 + 1000 / TICK_HZ)
    {
      // we average the wind direction during that time and store the data point in a circular/rolling buffer
      wn_raw_wind_report_t vane_raw_report;
      VaneAverager.computeReportFromAccumulatedValues(&vane_raw_report);
      wn_raw_wind_sample_t raw_sample = {speed_pulse_count, vane_raw_report.dir_avg, true};

      // reset pulse counter as soon as sample is recorded
      speed_pulse_count = 0;
      last_sampling_window_millis = millis();

      RollingBuffer.addRawSample(raw_sample);

      wn_instant_wind_sample_t instant_wind_sample = formatRawSample(raw_sample);
      // trigger the instant wind callback set by user
      triggerInstantWindCb(instant_wind_sample);
    }
    else
    {
      speed_pulse_count = 0;
      last_sampling_window_millis = millis();
    }
  }

  if (ticks_cnt % (_wind_update_period_sec * TICK_HZ) == 0)
  { // time interval between wind avg updates has elapsed
    wn_wind_report_t report = computeReportForRecentPeriodInSec(_wind_average_period_sec);
    triggerAvgWindCb(report);
  }
}

// Compute wind report over the most recent interval (seconds).
wn_wind_report_t WN_Core::computeReportForRecentPeriodInSec(uint16_t period)
{
  return computeReportForPeriodInSecIndexedFromLast(period, 0);
}

// Return the formatted wind sample indexed from the newest sample in the rolling buffer.
wn_instant_wind_sample_t WN_Core::getSampleIndexedFromLast(uint16_t index)
{
  wn_raw_wind_sample_t raw_sample = RollingBuffer.get(index);
  return formatRawSample(raw_sample);
}
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

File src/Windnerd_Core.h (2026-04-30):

/*
 * Copyright (c) 2025, windnerd.net
 * All rights reserved.
 *
 * This source code is licensed under the BSD 3-Clause License found in the
 * LICENSE file in the root directory of this source tree.
 */

#pragma once
#include "Arduino.h"
#include "Windnerd_Rolling_Buffer.h"
#include "Windnerd_Vector_Averager.h"

// LED pins for WindNerd Core board
#define CORE_SPEED_LED_PIN PA7
#define CORE_NORTH_LED_PIN 17

// Pulse/speed input pin for WindNerd Core board
#define CORE_SPEED_INPUT_PIN 25

// I2C pins for WindNerd Core board
#define CORE_SDA_PIN 23
#define CORE_SCL_PIN 22


typedef struct
{
  float speed = 0;
  uint16_t dir = 0;
} wn_instant_wind_sample_t;

typedef struct
{
  float avg_speed = 0;
  uint16_t avg_dir = 0;
  float min_speed = 0;
  float max_speed = 0;
} wn_wind_report_t;

typedef enum
{
  UNIT_MS = 0,
  UNIT_KN,
  UNIT_KPH,
  UNIT_MPH
} wn_wind_unit_t;

class WN_Core
{
public:
  // Constructor
    WN_Core(
      uint8_t speed_led_pin = CORE_SPEED_LED_PIN,
      uint8_t north_led_pin = CORE_NORTH_LED_PIN,
      uint8_t speed_input_pin = CORE_SPEED_INPUT_PIN,
      uint8_t scl_pin = CORE_SCL_PIN,
      uint8_t sda_pin = CORE_SDA_PIN
    );
  void loop(void);
  // set a callback function that will be triggered  every 3 sec for instant wind update
  void onInstantWindUpdate(void (*cb)(wn_instant_wind_sample_t instant_report));
  void triggerInstantWindCb(wn_instant_wind_sample_t &instant_report);

  // set a callback function that will be triggered every 1 minute for average wind update, the
  void onNewWindReport(void (*cb)(wn_wind_report_t report));
  void triggerAvgWindCb(wn_wind_report_t &report);

  void begin();
  bool setAveragingPeriodInSec(uint16_t period);
  bool setReportingIntervalInSec(uint16_t period);
  void setFrequencyToWindSpeedRatio(float ratio);
  void setSpeedUnit(wn_wind_unit_t unit);
  void invertVanePolarity(bool should_invert);
  void enableLowPowerMode();
  void disableLowPowerMode();
  bool isLowPowerMode();
  uint8_t getI2cError();
  wn_wind_report_t computeReportForRecentPeriodInSec(uint16_t period);
  wn_wind_report_t computeReportForPeriodInSecIndexedFromLast(uint16_t period, uint16_t index);
  wn_instant_wind_sample_t getSampleIndexedFromLast(uint16_t index);

private:
  float _HZ_to_ms;
  uint16_t _timeBetweenRefresh;
  uint8_t _speed_led_pin;
  uint8_t _north_led_pin;
  uint8_t _speed_input_pin;
  uint8_t _scl_pin;
  uint8_t _sda_pin;


  uint16_t _wind_average_period_sec;
  uint16_t _wind_update_period_sec;
  uint32_t ticks_cnt = 0; // ticks counter to be used as time base for periodic functions
  wn_wind_unit_t _unit_in_use = UNIT_MS;
  bool _invert_polarity = false;

  long last_sampling_window_millis = 0;

  WN_ROLLINGBUFFER RollingBuffer;
  WN_VECTOR_AVERAGER VaneAverager;

  void (*instantWindCb)(wn_instant_wind_sample_t instant_report) = nullptr;
  void (*avgWindCb)(wn_wind_report_t report) = nullptr;
  wn_wind_report_t formatRawReport(wn_raw_wind_report_t &raw_report);
  wn_instant_wind_sample_t formatRawSample(wn_raw_wind_sample_t &raw_sample);

  float pulsesToSpeedUnitInUse(float pulses);
  void signalIfNorth(uint16_t angle);
};

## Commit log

2025-10-13 drop sample when tick missed
    [Windnerd_Core.cpp, Windnerd_Core.h]
2025-10-30 board selection screenshots
2025-10-30 board selection correction
2025-10-30 low power mode
2026-03-07 fix voltage decimal
2026-03-07 STM32CubeProgrammer installation
2026-03-08 don't reboot at post_cnt 0
    [02-lte-modem-A7670X.ino]
2026-04-30 bitbang i2c when transmission error
    [Windnerd_Core.cpp, Windnerd_Core.h, Windnerd_TMAG5273.cpp]
2026-05-02 wtp temp_in, meta + doc fix
    [Windnerd_Wtp_Payload.h]
2026-05-18 leds open drain option
2026-05-27 split I2C

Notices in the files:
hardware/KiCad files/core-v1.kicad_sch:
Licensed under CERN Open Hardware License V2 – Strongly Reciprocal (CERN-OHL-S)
